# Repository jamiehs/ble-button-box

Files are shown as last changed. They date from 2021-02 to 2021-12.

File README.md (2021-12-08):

# Bluetooth Button Box

This is code that I run on a Huzzah32 Feather from Adafruit. It lives inside of the button box of my sim racing wheel. This gives me 3 encoders, a "funky switch", & 20+ buttons, all wirelessly. The Huzzah 32 ESP32 board has a BMS built in, and will charge the lithium cell whether the board is powered or not. I use a magnetic USB-Micro-B connector for quick connect and disconnect for charging. with ~1400 mAh in the cell I can get close to 24 hours of continuous on time.

* Originally forked from [Magnus Thome's implementation](https://github.com/MagnusThome/ESP32-BLE-Gamepad).
* Uses [John Main's code from www.best-microcontroller-projects.com](https://www.best-microcontroller-projects.com/rotary-encoder.html).
* Huzzah32 Battery Level code adapted from [Jon Froehlich's contrubution](https://github.com/makeabilitylab/arduino/commit/0b58c0b3b3194f50a81efa4008637b5f90e681fb).

## Parts List

* Micro controller [Adafruit HUZZAH32 – ESP32 Feather Board](https://www.adafruit.com/product/3405) (other ESP32 boards should work fine too)
* Ball spring detent encoders: [PEC11H-4020F-S0016](https://www.mouser.com/ProductDetail/652-PEC11H4020FS0016/) (most 6mm encoders will fit fine)
* Multi direction switch [RKJXT1F42001](https://www.mouser.com/ProductDetail/688-RKJXT1F42001/)  (funky switch)
* 12MM Tactile Switch 260GF 7.3MM [653-B3F-4155](https://www.adafruit.com/product/1009)
* i2c display module [SSD1306 (128x32)](https://www.amazon.com/gp/product/B08L7QW7SR)
* 3.7V Lipo cell with JST PH 2-Pin connector.  
*CHECK POLARITY OF THE CONNECTOR!* De-pin and swap the connector's pins if necessary: [Adafruit](https://www.adafruit.com/product/2011) or [Amazon](https://www.amazon.com/gp/product/B08FD39Y5R)
* 3D printed parts in the [STL directory](./stl); you'll probably design your own enclosure though.
* Power switch (SPST). This is used to ground the `EN` pin which shuts off the 3.3V regulator but leaves the charging circuit powered.

### Prerequisites

* Install the Arduino IDE
* Install the board definitions for the ESP32
* Install the needed libraries (listed below)

```cpp
#include <Adafruit_GFX.h>     // https://github.com/adafruit/Adafruit-GFX-Library
#include <Adafruit_SSD1306.h> // https://github.com/adafruit/Adafruit_SSD1306
#include <ESP32Encoder.h>     // https://github.com/madhephaestus/ESP32Encoder/
#include <Keypad.h>           // https://github.com/Chris--A/Keypad
#include <BleGamepad.h>       // https://github.com/lemmingDev/ESP32-BLE-Gamepad
```

### Wiring

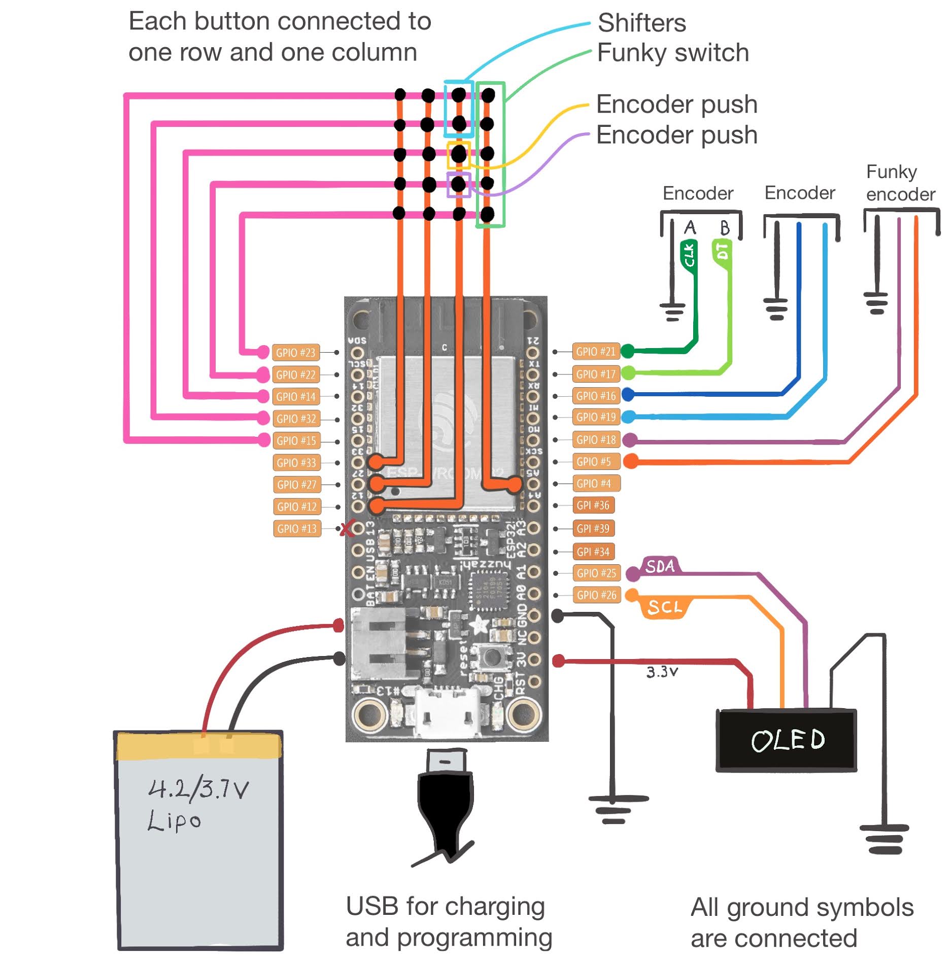
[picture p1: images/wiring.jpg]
Huzzah 32 Wiring Diagram


#### Button Matrix

You can use one button matrix for all of your push buttons, your shifters, and the encoder push function. Wiring it this way is more difficult/confusing than simply using one GPIO per button, but it's far more efficient (uses fewer pins).

**A note about Pin `13`** I was not able to use GPIO `13` for the button matrix (I was experiencing glitching in the matrix with all the other buttons). You may have more luck using it. I swapped the pin over to GPIO `4` afterwards.

There should be no reason you couldn't add more rows or columns to the matrix using GPI `36`, `39`, `34`, and GPIO `13`; if they are avaialble in your final wiring plan. I have not tested this.

#### Power Switch

You have two options. You can either connect your switch between `EN` and `GND` or you can just add the switch between the positive lead of your Lipo cell. Using the `EN` pin is easier, but there could be reasons you want to switch it at the power source. This is up to you.

#### Encoders

There should be no reason you couldn't add two more encoders to the layout (if you wanted to) using GPI `36`, `39`, `34`, and GPIO `13`; if they are avaialble in your final wiring plan. I have not tested this.

#### OLED Screen & Custom i2c Pins

I adde the OLED screen after the encoders and buttons were already mapped & built. At the time I had no idea I would have wanted to add an i2c device, so I used the Huzzah's default i2c pins for the button matrix (GPIOs `22` & `23`). With the ESP 32, you can just re-assign these in the `Wire.begin()`, so in the provided code, I have assinged them to GPIOs `25` & `26`.

```cpp
// Custom i2c pins and address for Adafruit OLED library
Wire.begin(CUSTOM_I2C_SDA, CUSTOM_I2C_SCL, SCREEN_ADDRESS);
```

-----

### Board Settings

These are my VS Code settings for interfacing with the board (your port will be different):
```json
{
    "port": "COM6", // find your Port and use it here
    "board": "esp32:esp32:featheresp32",
    "configuration": "FlashFreq=80,UploadSpeed=921600,DebugLevel=none,PartitionScheme=default",
    "sketch": "ble_button_box.ino",
    "output": "../build"
}
```

### Button Matrix

I'm not using any diodes, but you can implement them if you need to. I am using a 5x4 matrix for a total of 20 buttons:

```cpp
#define ROWS 5
#define COLS 4
uint8_t rowPins[ROWS] = {15, 32, 14, 22, 23};
uint8_t colPins[COLS] = {4, 12, 27, 33};
```

* 5 buttons for the funky switch (4 directions and push)
* 2 buttons for shifters (microswitches)
* 2 buttons for the encoders (push)
* 11 face buttons (push)

You need to define the HID button numbers you want the matrix buttons to identify as. In my example I am just counting up from `1..20` (you can tell that I counted incorrectly and skipped `4` while starting from `0`; no matter).

```cpp
byte keymap[ROWS][COLS] = {
  { 0, 1, 2, 3},
  { 5, 6, 7, 8},
  { 9,10,11,12},
  {13,14,15,16},
  {17,18,19,20}
};
```

### Funky Switch Issues

A note about the funky switch; you may notice that I'm doing some strange stuff here:

```cpp
#define FUNKY_DIR_COUNT 4
#define FUNKY_DIR_HOLDOFF_TIME 300 // 0.3sec
unsigned long funkyDirectionLastHoldoff[4] = {0,0,0,0};
char funkyCenterCode = 0;
char funkyDirectionCodes[FUNKY_DIR_COUNT] = {13, 9, 5, 17};
bool handlingFunkySwitch = false;
```

The Alps funky switch presses the center push for every direction press; it's hardwired that way. In order to code around this, I am checking to see if one of the four directions is pressed (the funky switch ended up being the first column [`0`, `5`, `9`, `13`, `17`] in my wiring). The array defines the `up`, `left`, `right`, `down` directions and the code iterates through it all later on.

If one of the cardinal directions is being pressed, we send _only_ that button code and stop processing the matrix.

We also need to have a holdoff time implemented to prevent bouncing.

```cpp
// Loops through the funky switch directions and checks to see if the push is being triggered
// along with another direction. If it is, we will flag it for skipping the normal press
// routine. We also press the _intended_ direction only.
for (int i = 0; i < FUNKY_DIR_COUNT; i++) {
  // if center not handling press, try directions.
  if(customKeypad.findInList((char) funkyCenterCode) != -1 && customKeypad.findInList((char) funkyDirectionCodes[i]) != -1) {
    if(now - funkyDirectionLastHoldoff[i] > FUNKY_DIR_HOLDOFF_TIME) {
      pressKey((char) funkyDirectionCodes[i]);
      funkyDirectionLastHoldoff[i] = now; // last press send
    }
    if (funkyDirectionLastHoldoff[i]==0) funkyDirectionLastHoldoff[i] = 1;   // SAFEGUARD WRAP AROUND OF millis() (WHICH IS TO 0) SINCE holdoff[i]==0 HAS A SPECIAL MEANING ABOVE
    handlingFunkySwitch = true;
  }
}
```

I'm sure there's a more elegant way to handle this, but I'm just not seeing it.

### Encoders

You will need to assign pins and "buttons" for your encoders too!

```cpp
//////////////////////////////////////////////////
// John Main "Robust Rotary encoder" Setup
//////////////////////////////////////////////////
// The `PEC11H-4020F-S0016` encoders I used from the BOM are
// very noisy and cause issues and double counts when used
// with the ESP32Encoder library. John's code works well!
#define ENCODER_COUNT 2
uint8_t uppPin[ENCODER_COUNT] = {16, 18}; // A pins
uint8_t dwnPin[ENCODER_COUNT] = {19, 5};  // B pins
uint8_t encCount[ENCODER_COUNT] = {0, 0};
uint8_t encValue[ENCODER_COUNT] = {0, 0};
uint8_t encPrevNextCode[ENCODER_COUNT] = {0, 0};
uint16_t encStore[ENCODER_COUNT]= {0, 0};
uint8_t encoderUpp[ENCODER_COUNT] = {23,25}; // Up buttons
uint8_t encoderDwn[ENCODER_COUNT] = {24,26}; // Down buttons
static int8_t rotEncTable[] = {0,1,1,0,1,0,0,1,1,0,0,1,0,1,1,0};

//////////////////////////////////////////////////
// ESP32Encoder Setup
//////////////////////////////////////////////////
// The `RKJXT1F42001` encoder works really well with the
// ESP32Encoder library, and does not work very well with
// the implemented "Robust Rotary encoder" solution.
unsigned long funkyEncoderHoldoff = 0;
int32_t funkyEncoderPrevCenter = 0;
uint8_t funkyEncoderUppPin = 21; // A pin
uint8_t funkyEncoderDwnPin = 17; // B pin
uint8_t funkyEncoderUpp = 22; // Up button
uint8_t funkyEncoderDwn = 21; // Down button
#define FUNKY_HOLDOFF_TIME 30
ESP32Encoder funkyEncoder;
```

Here the encoders are listed as columns. In this example, `16`, `19` are one encoder, and `18`, `5` are another, etc.

Likewise, when the encoder attached to `16`, `19` is rolled up or down, it'll press the gamepad buttons: `23`, `24`. These can be assigned to whatever you need them to be.

### Battery Level

Battery voltage and percentage reading is implemented.

```cpp
getBatteryVoltage();
getBatteryPercent();
```

Currently it sends the percent reading to the Bluetooth host every 5 minutes. The display code will later be updated to display this upon a button press combination (or perhaps holding a specific button for a few seconds).

Depending on your board, cell, and multimeter, you may need to adjust the vRef value.
```cpp
const float vRef = 1.048; // should be 1.1V but may need to be calibrated
```

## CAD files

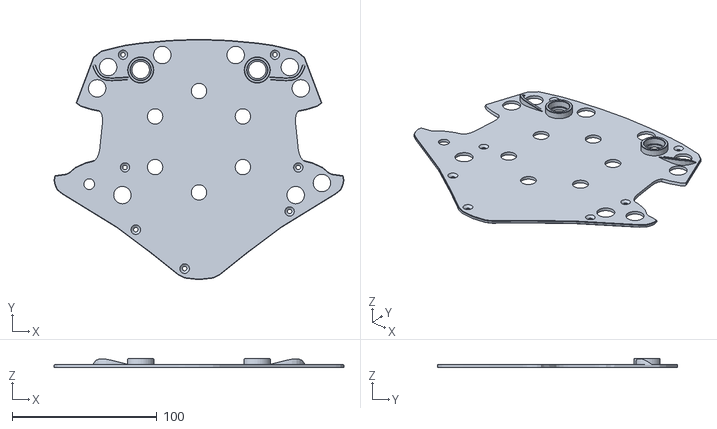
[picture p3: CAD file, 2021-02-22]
stl/faceplate.stl
200.3 x 166.1 x 6.33

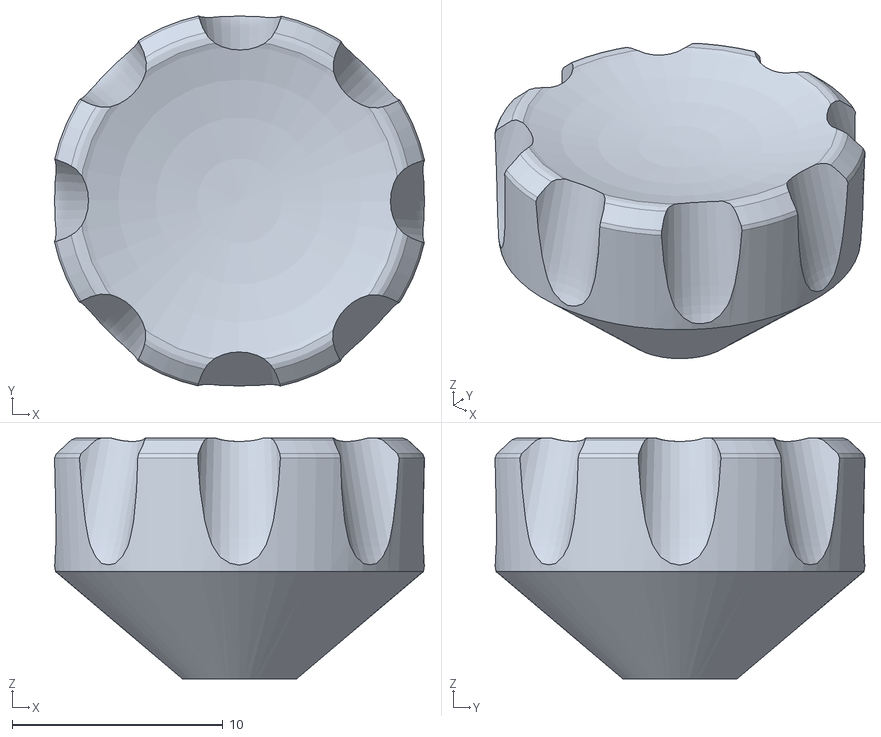
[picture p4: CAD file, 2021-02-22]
stl/funky switch knob.stl
17.5 x 17.5 x 11.4

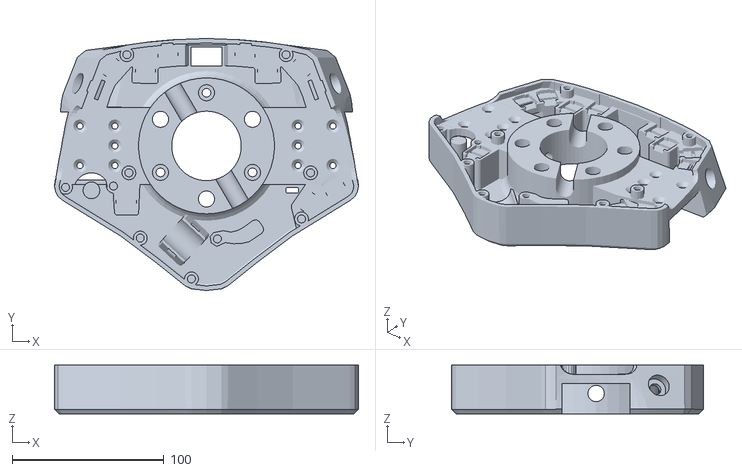
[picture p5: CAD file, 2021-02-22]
stl/button box.stl
200.3 x 166.1 x 32.0

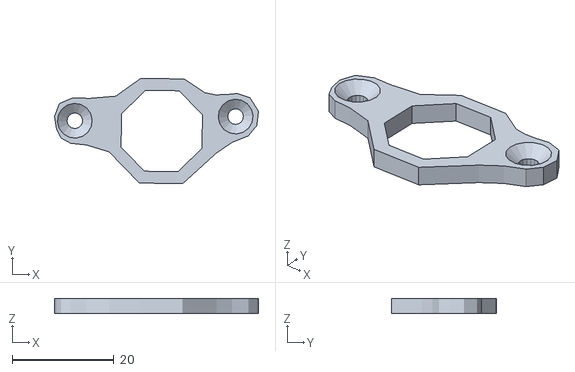
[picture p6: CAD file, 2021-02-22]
stl/multi-direction-switch-clamp.stl
40.0 x 20.7 x 3.00

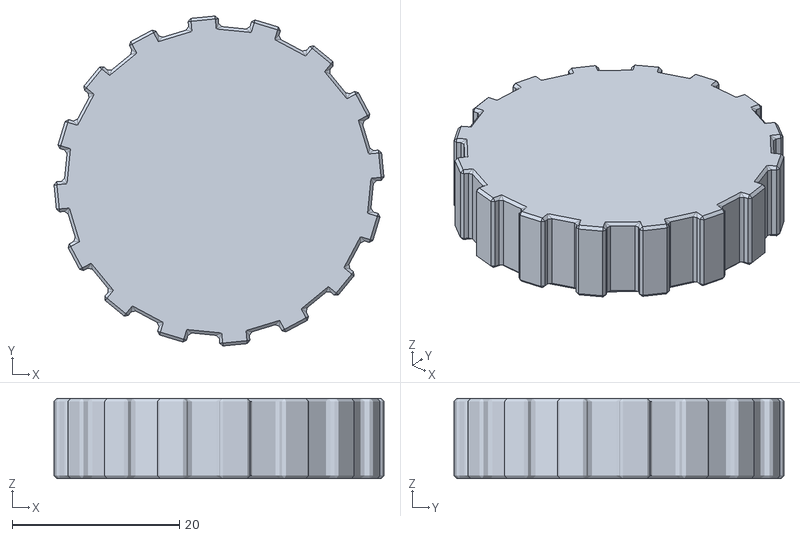
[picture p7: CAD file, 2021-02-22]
stl/knob with d hole.stl
39.5 x 39.5 x 9.59

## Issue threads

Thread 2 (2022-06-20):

Not all pins in matrix work

16sth, 2022-06-20:
I really wanted this sketch to work but after uploading to the Huzzah, it seems only pin 15 will connect to the other pins in the matrix showing in the windows game controller. In the serial monitor all pins are working as expected. Is this right or should all buttons light in the windows game controller? Thanks.

Navygator1878, 2024-04-11:
I also have the same problem now, I noticed that by moving the numbers on the matrix code some more buttons might work, but I'm doing random tests. it would be nice if the author would help us

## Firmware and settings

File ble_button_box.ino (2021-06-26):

#include <Wire.h>
#include <Adafruit_GFX.h>     // https://github.com/adafruit/Adafruit-GFX-Library
#include <Adafruit_SSD1306.h> // https://github.com/adafruit/Adafruit_SSD1306
#include <ESP32Encoder.h>     // https://github.com/madhephaestus/ESP32Encoder/
#include <Keypad.h>           // https://github.com/Chris--A/Keypad
#include <BleGamepad.h>       // https://github.com/lemmingDev/ESP32-BLE-Gamepad



//////////////////////////////////////////////////
// Adjustment Setup
//////////////////////////////////////////////////
bool debounceAdjustMode = false;



//////////////////////////////////////////////////
// Battery Polling Intervals
//////////////////////////////////////////////////
long batteryUpdateInterval = 300000; // every 5 minutes
// long batteryUpdateInterval = 1000; // 1 Hz (testing/fun)
long prevBatteryUpdate = 290000; // 10 seconds from goal



//////////////////////////////////////////////////
// OLED Screen Setup
//////////////////////////////////////////////////
#define SCREEN_WIDTH 128 // OLED display width, in pixels
#define SCREEN_HEIGHT 32 // OLED display height, in pixels
#define OLED_RESET    -1 // Reset pin # (or -1 if sharing Arduino reset pin)
#define SCREEN_ADDRESS 0x3C
#define CUSTOM_I2C_SDA 25
#define CUSTOM_I2C_SCL 26
Adafruit_SSD1306 display(SCREEN_WIDTH, SCREEN_HEIGHT, &Wire, OLED_RESET);



//////////////////////////////////////////////////
// BLE Gamepad Setup
//////////////////////////////////////////////////
BleGamepad bleGamepad("BLE Sim Buttons", "Arduino");



//////////////////////////////////////////////////
// Custom Keypad Matrix Setup
//////////////////////////////////////////////////
#define ROWS 5
#define COLS 4
uint8_t rowPins[ROWS] = {15, 32, 14, 22, 23};
uint8_t colPins[COLS] = {4, 12, 27, 33};
byte keymap[ROWS][COLS] = { // buttons
  { 0, 1, 2, 3},
  { 5, 6, 7, 8},
  { 9,10,11,12},
  {13,14,15,16},
  {17,18,19,20}
};
unsigned long keypadHoldoff[ROWS * COLS + 1] = {0};
unsigned short keypadHoldoffTime = 125;
Keypad customKeypad = Keypad( makeKeymap(keymap), rowPins, colPins, ROWS, COLS); 



//////////////////////////////////////////////////
// John Main "Robust Rotary encoder" Setup
//////////////////////////////////////////////////
// The `PEC11H-4020F-S0016` encoders I used from the BOM are
// very noisy and cause issues and double counts when used
// with the ESP32Encoder library. John's code works well!
#define ENCODER_COUNT 2
uint8_t uppPin[ENCODER_COUNT] = {16, 18}; // A pins
uint8_t dwnPin[ENCODER_COUNT] = {19, 5};  // B pins
uint8_t encCount[ENCODER_COUNT] = {0, 0};
uint8_t encValue[ENCODER_COUNT] = {0, 0};
uint8_t encPrevNextCode[ENCODER_COUNT] = {0, 0};
uint16_t encStore[ENCODER_COUNT]= {0, 0};
uint8_t encoderUpp[ENCODER_COUNT] = {23,25}; // Up buttons
uint8_t encoderDwn[ENCODER_COUNT] = {24,26}; // Down buttons
static int8_t rotEncTable[] = {0,1,1,0,1,0,0,1,1,0,0,1,0,1,1,0};



//////////////////////////////////////////////////
// ESP32Encoder Setup
//////////////////////////////////////////////////
// The `RKJXT1F42001` encoder works really well with the
// ESP32Encoder library, and does not work very well with
// the implemented "Robust Rotary encoder" solution.
unsigned long funkyEncoderHoldoff = 0;
int32_t funkyEncoderPrevCenter = 0;
uint8_t funkyEncoderUppPin = 21; // A pin
uint8_t funkyEncoderDwnPin = 17; // B pin
uint8_t funkyEncoderUpp = 22; // Up button
uint8_t funkyEncoderDwn = 21; // Down button
#define FUNKY_HOLDOFF_TIME 30
ESP32Encoder funkyEncoder;



//////////////////////////////////////////////////
// Funky Switch Direction Logic Setup
//////////////////////////////////////////////////
#define FUNKY_DIR_COUNT 4
#define FUNKY_DIR_HOLDOFF_TIME 300 // 0.3sec
unsigned long funkyDirectionLastHoldoff[4] = {0,0,0,0};
char funkyCenterCode = 0;
char funkyDirectionCodes[FUNKY_DIR_COUNT] = {13, 9, 5, 17};
bool handlingFunkySwitch = false;



void setup() {
  Serial.begin(115200);
  
  // Custom i2c pins and address for Adafruit OLED library
  Wire.begin(CUSTOM_I2C_SDA, CUSTOM_I2C_SCL, SCREEN_ADDRESS);

  // Initialize the OLED display
  display.begin();

  // Setup encoder logic for "John Main" encoders:
  // https://esp32.com/viewtopic.php?f=19&t=2881&start=30;
  for (uint8_t i=0; i<ENCODER_COUNT; i++) {
    pinMode(uppPin[i], INPUT);
    pinMode(uppPin[i], INPUT_PULLUP);
    pinMode(dwnPin[i], INPUT);
    pinMode(dwnPin[i], INPUT_PULLUP);
  }

  // Attach ESP32Encoder pins for "funky switch" (RKJXT1F42001) encoder
  funkyEncoder.attachHalfQuad(funkyEncoderUppPin, funkyEncoderDwnPin);
  funkyEncoder.clearCount();

  // Initialize Keypad Matrix & Options
  customKeypad.setHoldTime(7000); // 7 seconds is considered holding
  
  // Initialize BLE Gamepad
  bleGamepad.begin();

  Serial.println("Booted!");

  // Cheesy OLED boot message
  display.clearDisplay();
  display.setTextSize(2);
  display.setTextColor(SSD1306_WHITE);
  display.setCursor(0, 0);
  display.println("Ignition");
  display.println("Race Mode");
  display.display();
  delay(3000);
  display.clearDisplay();
}


void loop() {
  unsigned long now = millis();

  // Loop through "encoder table" encoders
  for (uint8_t i=0; i < ENCODER_COUNT; i++) {
    if(encValue[i] = readRotary(uppPin[i], dwnPin[i], i)) {
      encCount[i] +=encValue[i];
      Serial.print(encCount[i]);Serial.print(" ");

      if ( encPrevNextCode[i]==0x0b) {
          sendKey(encoderUpp[i]);
          Serial.print("UP ");
          Serial.println(encStore[i],HEX);
      }

      if ( encPrevNextCode[i]==0x07) {
          sendKey(encoderDwn[i]);
          Serial.print("DOWN ");
          Serial.println(encStore[i],HEX);
      }
    }
  }

  // Funky encoder is using ESP32Encoder routine
  int32_t cntr = funkyEncoder.getCount();
  if (cntr!=funkyEncoderPrevCenter) {
    if (!funkyEncoderHoldoff) {
      if(debounceAdjustMode) {
        // Adjust current debounce value
        unsigned short increment = 5;
        unsigned short minValue = 0;
        unsigned short maxValue = 500;
        if (cntr>funkyEncoderPrevCenter && keypadHoldoffTime + increment <= maxValue) {
          keypadHoldoffTime += increment;
        }
        if (cntr<funkyEncoderPrevCenter && keypadHoldoffTime - increment >= minValue) {
          keypadHoldoffTime -= increment;
        }
        // Display current debounce value
        displayDebounceMessage(keypadHoldoffTime);
      } else {
        // Normal funky encoder functionality
        if (cntr>funkyEncoderPrevCenter) { sendKey(funkyEncoderUpp); }
        if (cntr<funkyEncoderPrevCenter) { sendKey(funkyEncoderDwn); }
      }

      funkyEncoderHoldoff = now;
      // SAFEGUARD WRAP AROUND OF millis() (WHICH IS TO 0) SINCE funkyEncoderHoldoff==0 HAS A SPECIAL MEANING ABOVE
      if (funkyEncoderHoldoff==0) funkyEncoderHoldoff = 1;
    }
    else if (now - funkyEncoderHoldoff > FUNKY_HOLDOFF_TIME) {
      funkyEncoderPrevCenter = funkyEncoder.getCount();
      funkyEncoderHoldoff = 0;
    }
  }

  if (customKeypad.getKeys()) {
    // Loops through the funky switch directions and checks to see if the push is being triggered
    // along with another direction. If it is, we will flag it for skipping the normal press
    // routine. We also press the _intended_ direction only.
    for (int i = 0; i < FUNKY_DIR_COUNT; i++) {
      // if center not handling press, try directions.
      if(customKeypad.findInList((char) funkyCenterCode) != -1 && customKeypad.findInList((char) funkyDirectionCodes[i]) != -1) {
        if(now - funkyDirectionLastHoldoff[i] > FUNKY_DIR_HOLDOFF_TIME) {
          pressKey((char) funkyDirectionCodes[i], now);
          funkyDirectionLastHoldoff[i] = now; // last press send
        }
        if (funkyDirectionLastHoldoff[i]==0) funkyDirectionLastHoldoff[i] = 1;   // SAFEGUARD WRAP AROUND OF millis() (WHICH IS TO 0) SINCE holdoff[i]==0 HAS A SPECIAL MEANING ABOVE
        handlingFunkySwitch = true;
      }
    }

    // Scan the whole key list and find changed keys.
    for (int i=0; i < LIST_MAX; i++) {
      if (customKeypad.key[i].stateChanged) { // Only find keys that have changed state.
        switch (customKeypad.key[i].kstate) { // Report active key state : IDLE, PRESSED, HOLD, or RELEASED
          case PRESSED:
            if(handlingFunkySwitch == false){
              pressKey(customKeypad.key[i].kchar, now);
            }
          break;
          case HOLD:
            if(handlingFunkySwitch == false){
              holdKey(customKeypad.key[i].kchar);
            }
          break;
          case RELEASED:
          case IDLE:
            releaseKey(customKeypad.key[i].kchar);
          break;
        }

      }
    }
  }

  // Send battery level to host periodically
  if(now - prevBatteryUpdate > batteryUpdateInterval) {
    prevBatteryUpdate = now;
    int batteryLevel = getBatteryPercent();
    float batteryVoltage = getBatteryVoltage();

    Serial.print("battery: \t");
    Serial.println((String)batteryLevel);
    
    if(bleGamepad.isConnected()) {
      bleGamepad.setBatteryLevel(batteryLevel);
    }

    if(!debounceAdjustMode) {
      displayBatteryStats();
    }
  }

  // No longer looking for strange funky switch logic
  handlingFunkySwitch = false;
}

void sendKey(uint8_t key) {
  uint32_t gamepadbutton = pow(2,key); // CONVERT TO THE BINARY MAPPING GAMEPAD KEYS USE
  Serial.print("pulse\t");
  Serial.println(key);
  if(bleGamepad.isConnected()) {
    bleGamepad.press(gamepadbutton);
    delay(100); // there needs to be a press duration...
    bleGamepad.release(gamepadbutton);
  }
}

void pressKey(uint8_t key, unsigned long now) {
  if(now - keypadHoldoff[key] > keypadHoldoffTime) {
    keypadHoldoff[key] = now;

    // Disable Adjustment Mode
    if(debounceAdjustMode && key == 15) {
      debounceAdjustMode = false;
      displayBatteryStats();
      return;
    }

    // Handle regular button presses
    uint32_t gamepadbutton = pow(2,key);
    Serial.print("press\t");
    Serial.println(key);
    if(bleGamepad.isConnected()) {
      bleGamepad.press(gamepadbutton);
    }
  }
}

void holdKey(uint8_t key) {
  uint32_t gamepadbutton = pow(2,key);
  Serial.print("hold\t");
  Serial.println(key);

  // Enable Adjustment Mode
  if(!debounceAdjustMode && key == 15) {
    debounceAdjustMode = true;
    displayDebounceMessage(keypadHoldoffTime);
    return;
  }
}

void releaseKey(uint8_t key) {
  // Handle regular button releases
  uint32_t gamepadbutton = pow(2,key);
  Serial.print("release\t");
  Serial.println(key);
  if(bleGamepad.isConnected()) {
    bleGamepad.release(gamepadbutton);
  }
}

// https://www.best-microcontroller-projects.com/rotary-encoder.html
// A vald CW or  CCW move returns 1, invalid returns 0.
int8_t readRotary(uint8_t DATA_PIN, uint8_t CLK_PIN, uint8_t i) {
  static int8_t rotEncTable[] = {0,1,1,0,1,0,0,1,1,0,0,1,0,1,1,0};

  encPrevNextCode[i] <<= 2;
  if (digitalRead(DATA_PIN)) encPrevNextCode[i] |= 0x02;
  if (digitalRead(CLK_PIN)) encPrevNextCode[i] |= 0x01;
  encPrevNextCode[i] &= 0x0f;

   // If valid then store as 16 bit data.
   if  (rotEncTable[encPrevNextCode[i]] ) {
      encStore[i] <<= 4;
      encStore[i] |= encPrevNextCode[i];
      //if (encStore[i]==0xd42b) return 1;
      //if (encStore[i]==0xe817) return -1;
      if ((encStore[i]&0xff)==0x2b) return -1;
      if ((encStore[i]&0xff)==0x17) return 1;
   }
   return 0;
}

int getBatteryPercent() {
  const int maxDisplayed = 100; // 100% (higher values are constrained)
  const int minDisplayed = 0; // 0% or flat (we'll probably never get there)
  const float maxBatteryVoltage = 4.2; // Max LiPoly voltage of a 3.7 battery is 4.2
  const float minBatteryVoltage = 3.3; // cutoff voltage (3.2, 3.3 to be safer)
  float voltageLevel = getBatteryVoltage();
  float usablePercent = ((voltageLevel - minBatteryVoltage) / (maxBatteryVoltage - minBatteryVoltage)) * ((maxDisplayed - minDisplayed) + minDisplayed);
  return constrain((int)usablePercent, minDisplayed, maxDisplayed);
}

// If you read voltage values higher than 4.2, and are seeing a difference
// between the value on your multimeter, adjust the vRef. Something between
// 1.0 and 1.1 should be where you're aiming for.
// You can go as deep as you want here:
// https://esp32.com/viewtopic.php?f=19&t=2881&start=30;
// the simple fix below works for me though.
float getBatteryVoltage() {
  const float vrefCalibration = 0.9417;
  const float vRef = 1.1; // should be 1.1V but may need to be calibrated above
  const float maxAnalogVal = 4095.0; // defines the range of the ADC calculation
  return (analogRead(35) / maxAnalogVal) * 2 * (vRef * vrefCalibration) * 3.3; // calculate voltage level
}

void displayBatteryStats() {
  int batteryLevel = getBatteryPercent();
  float batteryVoltage = getBatteryVoltage();

  display.clearDisplay();
  display.setTextSize(2);
  display.setTextColor(SSD1306_WHITE);
  display.setCursor(0, 0);
  display.println((String)batteryVoltage + "V");
  display.println((String)batteryLevel + "%");
  display.display();
}

void displayDebounceMessage(unsigned short holdoff) {
  display.clearDisplay();
  display.setTextSize(2);
  display.setTextColor(SSD1306_WHITE);
  display.setCursor(0, 0);
  display.println("Debounce");
  display.println((String)holdoff + "ms");
  display.display();
}

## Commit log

2021-02-01 Refactor/cleanup * Changes BLE library * Attempts to fix battery code
    [ble_button_box.ino]
2021-02-22 swaps order of definitions
    [ble_button_box.ino]
2021-02-22 Adds STL files
    [button box.stl, faceplate.stl, funky switch knob.stl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]
2021-06-06 Adds battery level fix Removes delay Adds holdoff to funky switch
    [ble_button_box.ino]
2021-06-07 Adds dual encoder logic, battery fix
    [ble_button_box.ino]
2021-06-09 Corrects battery math Switches to periodic reporting
    [ble_button_box.ino]
2021-06-09 Maps battery level to usable range
2021-06-13 Refactors battery voltage code Adds notes to setup sections
2021-06-13 Moves battery functions to end
2021-06-16 Wait a little longer before querying the battery
2021-06-17 Updates calibration for "production" module.
2021-06-26 Adds wiring section
2021-06-26 Adds holdoff (debouncing) for button sends, and also adds a quick and dirty interactive adjustment mode on the OLED.
2021-07-09 Revert "Lowering clock speed; just curious of the impact, if any."
    This reverts commit 8b5deb9bd032f1b6d581aad6d0b245a5299ab3f5.
    [ble_button_box.ino]
2021-07-09 Revert "Uses debouncing built into Keypad lib" I'm not sure this is an improvement from my own debouncing.
    This reverts commit e7584fa8410bd07e1c2a4edf19fba2bca74b4d08.
    [ble_button_box.ino]
2021-12-08 Updates link to buttons
